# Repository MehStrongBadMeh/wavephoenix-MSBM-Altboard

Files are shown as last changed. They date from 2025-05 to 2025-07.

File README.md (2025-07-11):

<h1 align="center">
    WavePhoenix-MSBM-Altboard
</h1>

<p align="center">
    An alternate board design for the WavePhoenix Nintendo WaveBird open-source receiver 
</p>

<p align="center">
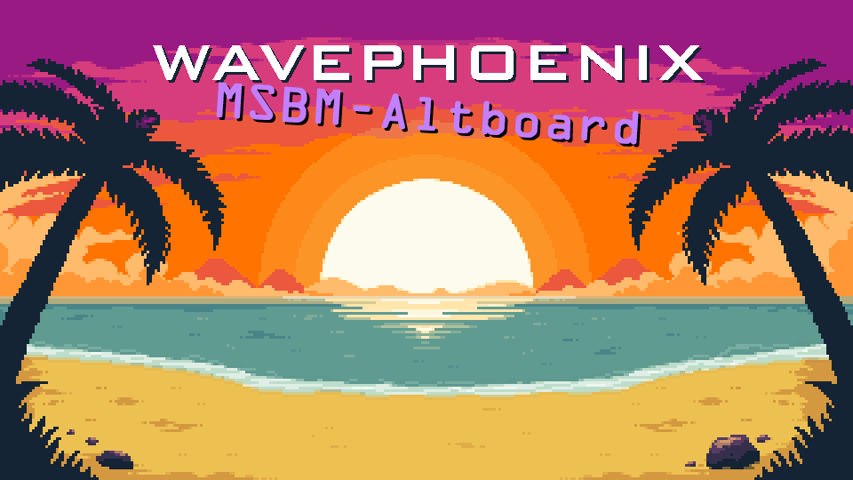
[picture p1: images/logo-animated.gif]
WavePhoenix-MSBM-Altboard
    
</p>

## Motivation

loopj's Wavephoenix receiver design relies on the RF-Star RF-BM-BG22C3 SoC, which quickly became out-of-stock everywhere, potentially due to people wanting them to make WavePhoenix receivers. So, I set out looking for an alternative. I ended up stumbling upon the [RF-BM-BG22A3](https://www.rfstariot.com/rf-bm-bg22a3-ble5-3-efr32bg22-module_p81.html) which utillizes the same SoC, in a slightly larger package. This means that, if wired properly, it could use the same firmware as the stock Wavephoenix board without modifications. All that was needed was an updated PCB design to utillize this alternate package, and a reworked case to fit the new PCB. The result is slightly bigger than the stock Wavephoenix, but still quite a bit smaller than the original Wavebird receiver.

As a bonus, the pcb antenna in the RF-BM-BG22A3 has great range. I have clocked over 40 feet of range without noticing dropouts.

## Firmware

The WavePhoenix-MSBM-Altboard is identical to the stock firmware of the WavePhoenix, [which can be found here](https://github.com/loopj/wavephoenix).

## Hardware

The hardware for the WavePhoenix-MSBM-Altboard receiver variant is available in the [`hardware/mini-receiver-msbm-altboard`](hardware/mini-receiver-msbm-altboard) directory. The receiver is similar to the reference WavePhoenix receiver other than the replacement of the RF-BM-BG22C3 with the RF-BM-BG22A3.

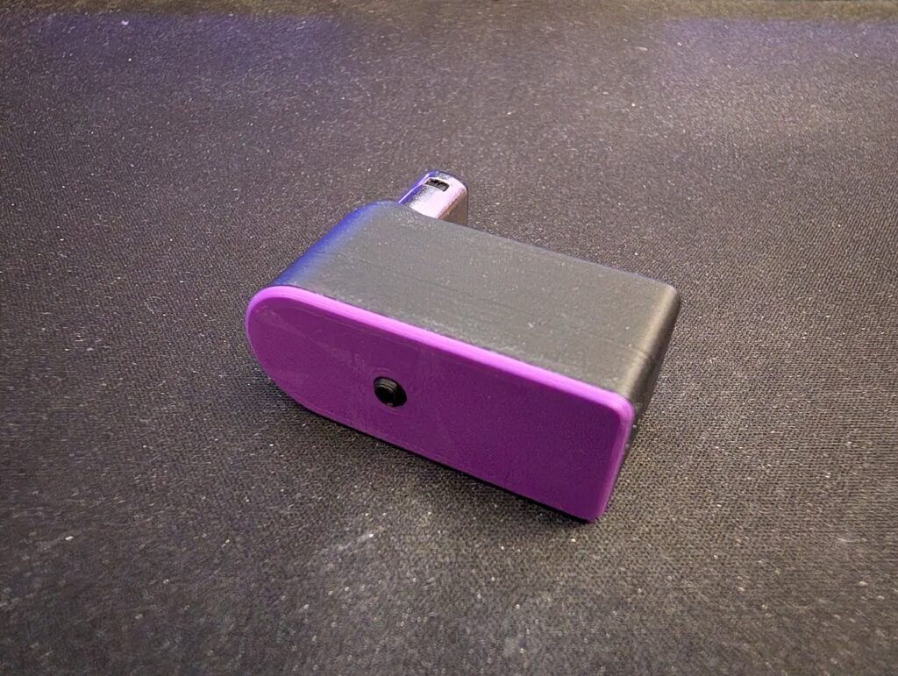
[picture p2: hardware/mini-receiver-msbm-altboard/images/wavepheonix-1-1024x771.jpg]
WavePhoenix-MSBM-Altboard Mini Receiver
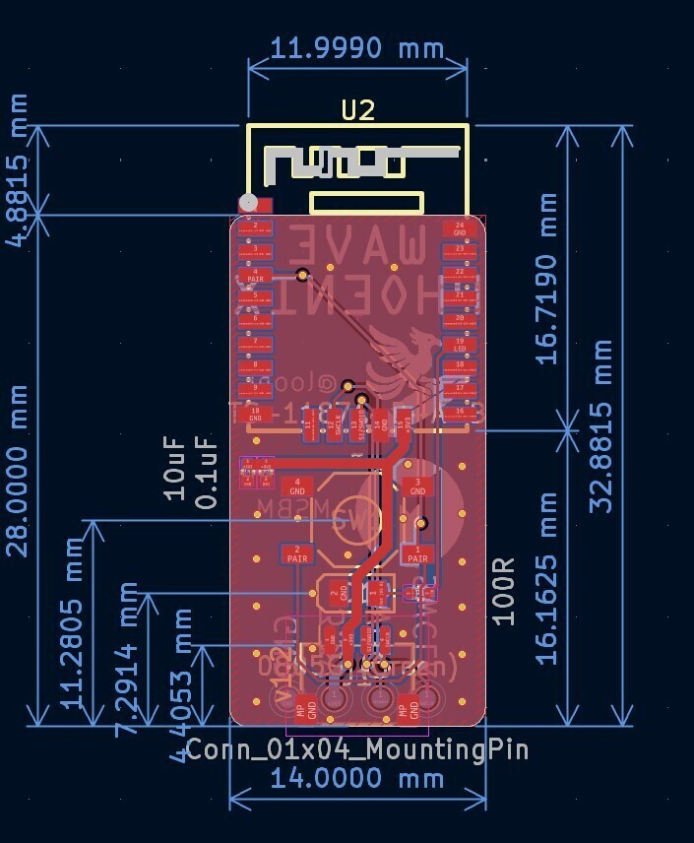
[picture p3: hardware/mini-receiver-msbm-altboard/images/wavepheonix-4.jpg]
WavePhoenix-MSBM-Altboard Mini Receiver
 

The hardware folder contains a simple PCB which hosts a [RF-BM-BG22A3](https://www.rfstariot.com/rf-bm-bg22a3-ble5-3-efr32bg22-module_p81.html) module, a pairing button, a status LED, and a JST connector for connecting to a GameCube controller port, as well as a 3D printable case.

- [`case`](hardware/mini-receiver-msbm-altboard/case) - 3D printable case for the receiver
- [`case-usb`](hardware/mini-receiver-msbm-altboard/case-usb) - 3D printable case for a special USB variant of the receiver
- [`gerbers`](hardware/mini-receiver-msbm-altboard/gerbers) - Gerber files for ordering the PCB
- [`KiCad`](hardware/mini-receiver-msbm-altboard/KiCad) - KiCad project files for the PCB

Check out the [`hardware/mini-receiver-msbm-altboard/README.md`](hardware/mini-receiver-msbm-altboard/README.md) for more information on how to build your own receiver based on this hardware variant.

## Special Thanks

- [loopj](https://github.com/loopj) - for creating the original WavePhoenix firmware and hardware that this variant is based on
- [dwillmore](https://github.com/dwillmore) and [unicab369](https://github.com/unicab369) - for giving me a crash course in using KiCad

## License

The hardware is licensed under the [Solderpad Hardware License v2.1](hardware/LICENSE).

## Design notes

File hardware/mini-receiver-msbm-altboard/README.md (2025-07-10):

# WavePhoenix-MSBM-Altboard Mini Receiver

The WavePhoenix-MSBM-Altboard Mini Receiver is a small, low-cost WaveBird receiver replacement based on the original WavePhoenix design. It has been designed to use an alternate chipset but otherwise function identically.

The receiver uses a cheap, off-the-shelf wireless module (the [RF-BM-BG22A3](https://www.rfstariot.com/rf-bm-bg22a3-ble5-3-efr32bg22-module_p81.html)), which can either be hand-wired, or assembled onto a custom PCB.

WavePhoenix-MSBM-Altboard Mini Receiver WavePhoenix-MSBM-Altboard Mini Receiver

## Differences

Functionally identical to the stock WavePhoenix other than:

- You need 1x RF-BM-BG22A3 module ([AliExpress](https://www.aliexpress.us/item/3256801502682253.html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), [LCSC](https://lcsc.com/product-detail/Bluetooth-Modules_RF-star-RF-BM-BG22A3_C5441203.html?s_z=n_RF-BM-BG22A3), [Tindie](https://www.tindie.com/products/rfstariot/efr32bg22-long-range-bluetooth-wireless-module/)) instead of the RF-BM-BG22C3
- The case has been designed to be used with a standard 1.6mm thick PCB instead of the 1.2mm thickness PCB the stock WavePhoenix was designed around.

## Build Guide

**This guide below is identical to the stock guide ([https://github.com/loopj/wavephoenix/tree/main/hardware/mini-receiver]), other than the differences listed above and some other minor additions**

### Parts

- Assembled Mini Receiver PCB - (see [PCB](#pcb))
- 3D printed case - (see [Case](#case))
- GameCube male connector - ([AliExpress](https://www.aliexpress.us/item/3256804501860592.html), [Alibaba](https://www.alibaba.com/product-detail/NGC-Gamecube-Male-Connector_1600107604838.html), [eBay](https://www.ebay.com/itm/354372477064))
- JST-SH 4-Pin connector with pre-crimped cable - ([AliExpress](https://www.aliexpress.us/item/3256803952186380.html), [Amazon](https://www.amazon.com/dp/B0D9WMLZ7B/))
- 1.5mm PMMA fiber cable - ([AliExpress](https://www.aliexpress.us/item/3256806278563564.html)) *or* 1.5mm diameter x 4mm light pipe - ([AliExpress](https://www.aliexpress.us/item/3256801194682892.html))
- Crimping tool or soldering iron (depending on the your connector type)

### Assembly

- Assemble the JST-SH to GameCube connector cable - (see [Cable](#cable))
- Flash the firmware - (see [Initial Firmware Flashing](#initial-firmware-flashing))
- Insert the GameCube connector into the case until it clicks into place
- Connect the JST-SH connector to the PCB
- Insert the PCB into the case, ensuring the LED and switch are aligned with the holes in the case, it should click into place
- Insert the light pipe into the small hole in the front of the case, if using PMMA fiber for the light pipe, cut it to size first (4mm)
- Insert the 3D printed button into the large hole in the front of the case
- Press the front of the case onto the back of the case

## PCB

The WavePhoenix Mini Receiver PCB is a simple carrier PCB for a RF-BM-BG22C3 module, tact switch, status LED, and a connector for the GameCube controller port.

### Ordering from JLCPCB, PCBWay, etc

You can find the gerber files in the [`gerbers`](gerbers) directory.

Order the PCB with the following settings:

- 2-layer board
- PCB thickness of **1.6mm**
- HASL is fine

### Bill of Materials

- **1x RF-BM-BG22A3 module ([AliExpress](https://www.aliexpress.us/item/3256801502682253.html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), [LCSC](https://lcsc.com/product-detail/Bluetooth-Modules_RF-star-RF-BM-BG22A3_C5441203.html?s_z=n_RF-BM-BG22A3), [Tindie](https://www.tindie.com/products/rfstariot/efr32bg22-long-range-bluetooth-wireless-module/))**
- 1x 0805 green LED
- 1x 5x5mm tactile switch
- 1x 4-pin JST-SH connector
- 1x 0402 100Ω resistor (adjust as needed)
- 1x 0402 10uF capacitor
- 1x 0402 0.1uF capacitor

You can find a [Mouser shared cart here](https://www.mouser.com/ProjectManager/ProjectDetail.aspx?AccessID=66aed3ee61). You'll need to source the RF-BM-BG22A3 module separately.

### Hand Assembly

The components should all be hand solderable, the smallest parts being the 0402 capacitors and resistor. If you are struggling with the capacitors, you can omit them, but it is recommended to include them.

I recommend using magnification, and soldering the RF-BM-BG22A3 module first, since the module is hard to solder once the capacitors are in place.

### PCB Assembly Services

If you want to use a PCB assembly service such as JLC PCBA, the CPL file and the BOM file are also found in the [`gerbers`](gerbers) directory.

**Notably, unlike the RF-BM-BG22C3, the RF-BM-BG22A3 qualifies for JLCPCB's Economic assembly, so this variant is considerably cheaper to get pre-assembled versus the stock WavePhoenix.**

## Case

A 3D printable case for the receiver can be found in the [`case`](case) directory. The case is designed to fit the assembled PCB and has a slot for the GameCube connector.

I recommend printing the parts in the default orientation of their STL.

## Case-USB

Oh ho ho, now what do we have here? Some kind of alternative case in the [`case-usb`](case-usb) that is designed to house both a WavePhoenix-MSBM-Altboard and a WaveShare RP2040-Zero. What purpose could that possbily serve? Guess you'll have to tune back in later to find out.

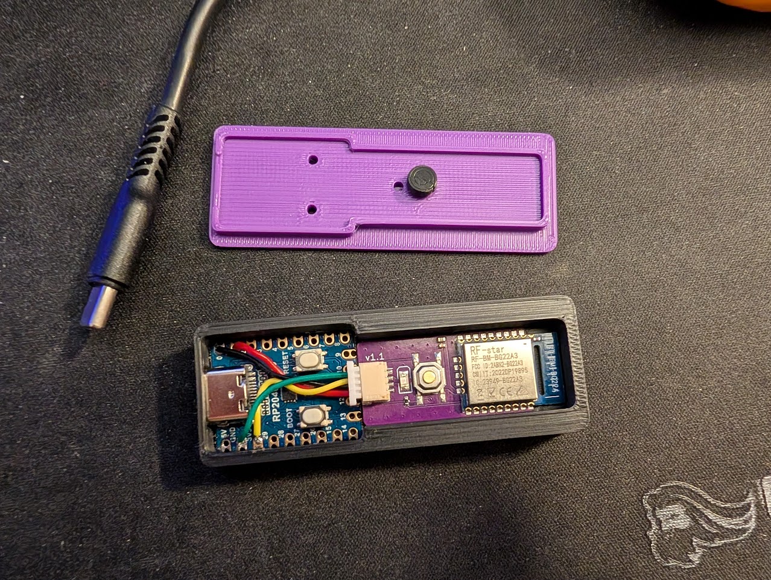
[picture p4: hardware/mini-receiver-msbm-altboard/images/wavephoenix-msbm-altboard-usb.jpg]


## Cable

> [!TIP]
> The [Fires Custom Controller](https://firescc.com/mod-guides#/diy-custom-cables) custom cable guide, covers the crimping the GameCube connector pins in detail!

Although we are using a 4-pin JST-SH connector, we only actually need 3 wires for the receiver. In the following photos, the ground wire is black, the power wire is red, and the data wire is blue, however the wire colors of pre-made JST cables vary *wildly*, so please check the pinout rather than relying on the wire colors in the photos.

Pin 1 on the JST-SH connector is indicated by a small triangle on the connector housing. In my photos below I have removed the unused wire from pin 4 of the JST-SH connector, but you can also leave it in place if you prefer.

First trim the wires on JST-SH connector cable to 30mm:

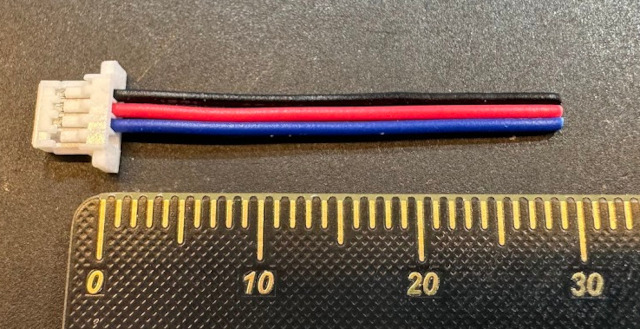
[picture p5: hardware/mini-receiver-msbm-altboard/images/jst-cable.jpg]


Strip a small amount of insulation (~1mm) off the ends of the wires, and crimp the wires to the GameCube connector pins.

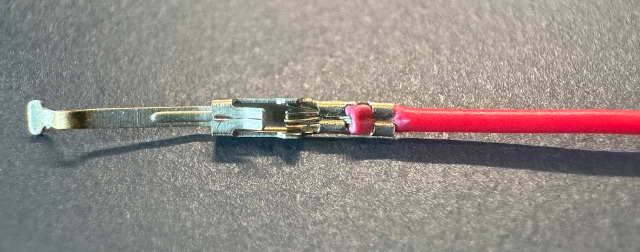
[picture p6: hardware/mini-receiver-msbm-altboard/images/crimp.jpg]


Insert the crimped pins into the GameCube connector housing in the following positions:

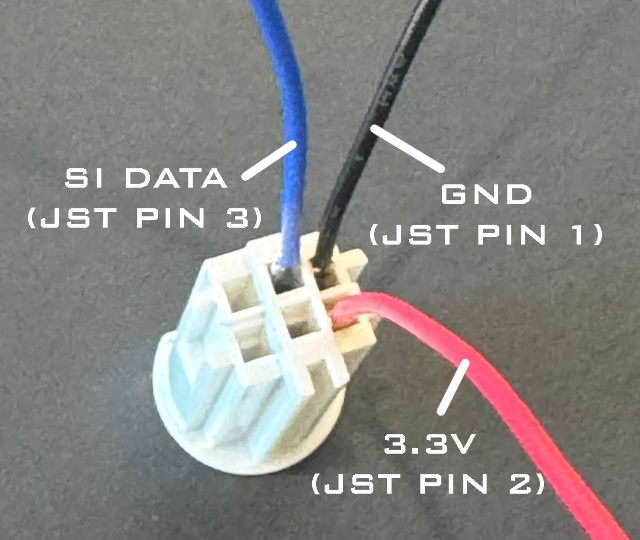
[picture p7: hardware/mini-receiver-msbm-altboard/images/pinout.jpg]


The “wings” on each pin should face towards the center of the plug, and the pins should be inserted until they click into place.

Next we need to trim off and file down the cable retention tabs on the metal GameCube connector housing:

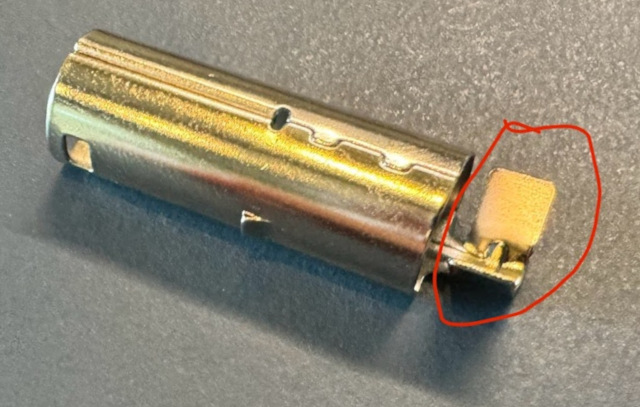
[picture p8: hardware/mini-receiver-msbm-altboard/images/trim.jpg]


We can then finally insert the plastic connector into the metal housing:

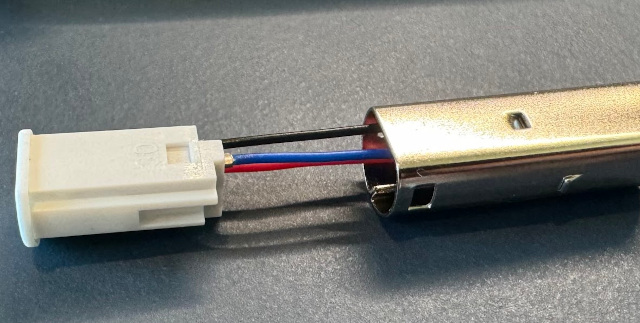
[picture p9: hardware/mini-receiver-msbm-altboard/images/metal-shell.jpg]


The complete assembly should look like this:

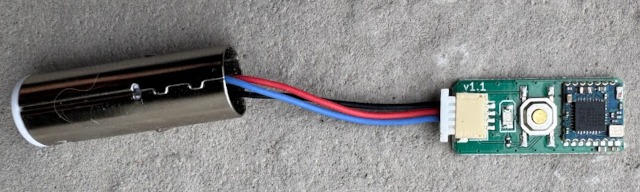
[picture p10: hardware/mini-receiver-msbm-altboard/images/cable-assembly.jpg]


## Initial Firmware Flashing

> [!NOTE]
> Once you have flashed the bootloader, you can use Bluetooth over-the-air updates to flash future firmware updates!

WavePhoenix receivers have two pieces of software running on them, the *bootloader* and the *application firmware*. The *bootloader* allows us to flash future application updates over Bluetooth, the *application firmware* is the program that handles WaveBird communication.

You can [find the latest bootloader and firmware here](https://github.com/loopj/wavephoenix/releases/latest), the WavePhoenix-MSBM-Altboard mini-receiver needs the `rf-bm-bg22c3` build of the firmware. **(Yes, the RF-BM-BG22A3 is compatible with it)**

The first-time flashing of the firmware requires a debug probe and some special software. If your WavePhoenix board already has the bootloader flashed, you can skip this part.

### Debug Probes

You'll need a SWD debug probe to flash the initial firmware onto the receiver. The debug probe connects to the receiver's SWD pins and allows you to flash the firmware using OpenOCD.

If you don't already have an SWD-capable debug probe, you can build one using a Raspberry Pi Pico. Instructions on how to build a debug probe using a Raspberry Pi Pico can be found in the [Appendix](#pi-pico-debug-probe).

### Pinouts

If you are flashing an assembled Mini Receiver board, the SWD pins are made available in two locations, pads on the back of the board, and via the 4-pin JST-SH connector.

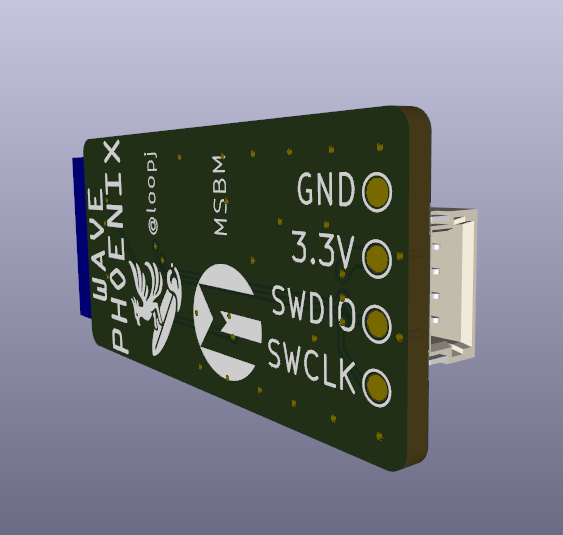
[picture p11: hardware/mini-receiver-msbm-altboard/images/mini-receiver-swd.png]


The pinout of the JST-SH connector is as follows:

| Pin | Function | Description |
| --- | --- | --- |
| 1 | GND | Ground |
| 2 | 3.3V | Power |
| 3 | SWDIO | SWD Data / GameCube Data |
| 4 | SWCLK | SWD Clock |

### OpenOCD

To flash the firmware, you'll need to install Arduino's fork of OpenOCD, which adds support for EFR32 Series 2 SoCs.

Prebuilt binaries are available for [Windows](https://downloads.arduino.cc/tools/openocd-0.12.0-arduino1-static-i686-w64-mingw32.tar.bz2), [macOS](https://downloads.arduino.cc/tools/openocd-0.12.0-arduino1-static-x86_64-apple-darwin19.tar.bz2), and [Linux](https://downloads.arduino.cc/tools/openocd-0.12.0-arduino1-static-x86_64-ubuntu16.04-linux-gnu.tar.bz2).

The source for this fork is available on [GitHub here](https://github.com/facchinm/OpenOCD/tree/arduino-0.12.0-rtx5).

### Flashing

Once you have OpenOCD installed, you can flash the bootloader and application firmware using the following commands:

#### Erase the device

First we'll need to do a full device erase:

```bash
# Linux / macOS
openocd -f "interface/cmsis-dap.cfg" \
        -f "target/efm32s2.cfg" \
        -c "init; efm32s2_dci_device_erase; shutdown"
```

```powershell
# Windows (PowerShell)
openocd.exe -f "interface\cmsis-dap.cfg" `
            -f "target\efm32s2.cfg" `
            -c "init; efm32s2_dci_device_erase; shutdown"
```

> [!IMPORTANT]  
> Disconnect then reconnect the debug probe to the receiver before proceeding to the next step.

#### Flash the bootloader

Then we can flash the bootloader:

```bash
# Linux / macOS
openocd -f "interface/cmsis-dap.cfg" \
        -c "transport select swd" \
        -f "target/efm32s2.cfg" \
        -c "init; halt; flash write_image erase bootloader.hex; exit"
```

```powershell
# Windows (PowerShell)
openocd.exe -f "interface\cmsis-dap.cfg" `
            -c "transport select swd" `
            -f "target\efm32s2.cfg" `
            -c "init; halt; flash write_image erase bootloader.hex; exit"
```

> [!TIP]  
> From this point on, you can now use Bluetooth over-the-air updates to flash new application firmware!

#### Flash the application

Since we already have the device wired up, we can also flash the receiver application using SWD:

```bash
# Linux / macOS
openocd -f interface/cmsis-dap.cfg \
        -c "transport select swd" \
        -f target/efm32s2.cfg \
        -c "init; halt; flash write_image erase receiver.hex; exit"
```

```powershell
# Windows
openocd.exe -f interface\cmsis-dap.cfg `
            -c "transport select swd" `
            -f target\efm32s2.cfg `
            -c "init; halt; flash write_image erase receiver.hex; exit"
```

You should now have a fully functional WavePhoenix receiver!

## Usage

### Pairing

WavePhoenix receivers use "virtual pairing" instead of the original WaveBird’s channel wheel. To initiate pairing, press the receiver’s pairing button. The onboard LED will start blinking to indicate the receiver is now in pairing mode. Press and hold X + Y on the WaveBird controller to pair a WaveBird to a receiver. Once pairing is successful, the LED will stop blinking and remain solid.

### Entering Bootloader Mode

You can enter the bootloader for OTA updates in two ways:

1. Press and hold the pairing button for more than 3 seconds, until the LED turns off
2. Press and hold the pairing button while plugging in the receiver

### Upgrading Firmware

You can always find the latest receiver firmware in the [latest release](https://github.com/loopj/wavephoenix/releases/latest) on GitHub. The firmware is available in two formats, a `.gbl` file for over-the-air updates, and a `.hex` file for flashing via SWD.

The mini receiver uses the `rf-bm-bg22c3` build of the firmware, which is specifically designed for the RF-BM-BG22C3 module.

#### Using the WavePhoenix Web App

If you have a computer with Bluetooth or an Android phone, you can use the [WavePhoenix Web App](https://web.wavephoenix.com) in Google Chrome to flash the firmware.

#### Using the WavePhoenix CLI

If you have a computer with Bluetooth, you can also use the [WavePhoenix CLI](https://github.com/loopj/wavephoenix-cli) to flash the firmware:

```bash
wavephoenix flash firmware.gbl
```

#### Using the Simplicity Connect app

Another option is to use the [Simplicity Connect mobile app](https://www.silabs.com/developer-tools/simplicity-connect-mobile-app?tab=downloads) to flash the firmware.

#### Flashing via SWD

You can also always use SWD to re-flash the firmware, as described in the [Initial Firmware Flashing](#initial-firmware-flashing) section.

## Appendix

### Pi Pico Debug Probe

If you have a Raspberry Pi Pico, you can use it as a debug probe to flash WavePhoenix firmware. The Pico is a low-cost (~$4) microcontroller board that can be used as a debug probe with OpenOCD.

Download the latest `debugprobe_on_pico.uf2` from the [Raspberry Pi Debug Probe repo](https://github.com/raspberrypi/debugprobe/releases/latest) and flash it to your Pico by dragging the file onto the Pico's USB drive. Once you have flashed the firmware, the Pico will now be available to use as a debug probe with OpenOCD.

Here's the pinout for SWD programming:

Pi Pico Debug Probe

### Flipper Zero Debug

If you are me, then you just used your Flipper Zero as a debug probe, just use the [Dap Link](https://lab.flipper.net/apps/dap_link) app and hook up the pins to the pins you selected in the app for SWC SWD.

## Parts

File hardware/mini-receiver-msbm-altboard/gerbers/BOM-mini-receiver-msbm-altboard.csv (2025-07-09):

Designator | Footprint | Quantity | Value | LCSC Part #
C1 | 0402 | 1 | 0.1uF | C1525
C2 | 0402 | 1 | 10uF | C15525
D1 | LED0805-R-RD | 1 | 0805G (Green) | C2297
J1 | JST_SH_SM04B-SRSS-TB_1x04-1MP_P1.00mm_Horizontal | 1 | Conn_01x04_MountingPin | C160404
R1 | 0402 | 1 | 100R | C25076
SW1 | SW-SMD_4P-L5.1-W5.1-P3.70-LS6.5-TL-2 | 1 | TS-1187A-B-A-B | C318884
U2 | BULETM-SMD_RF-BM-BG22A1 | 1 | ~ | C5441203

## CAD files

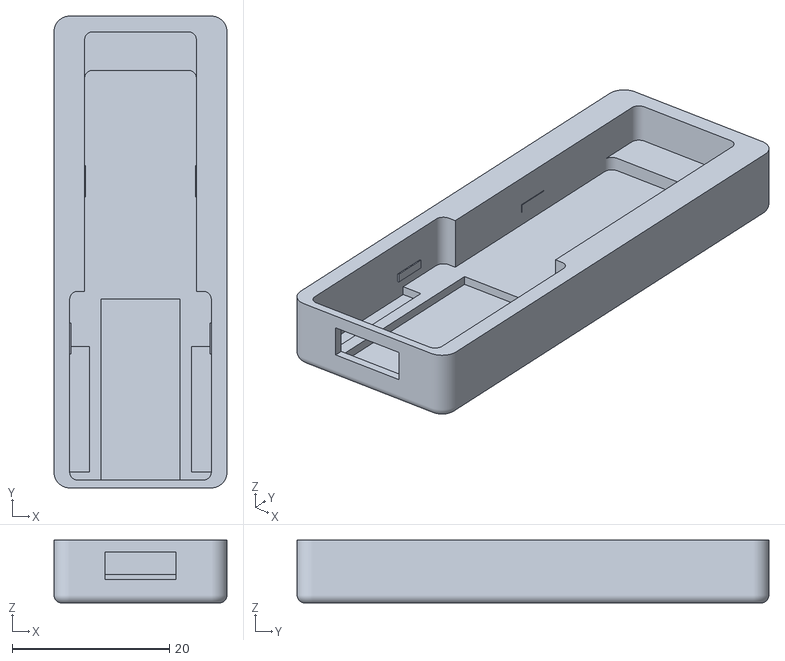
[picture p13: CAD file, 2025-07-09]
hardware/mini-receiver-msbm-altboard/case-usb/WavePhoenix-MSBM-Altboard-with-rp2040-zero-main.stl
22.0 x 60.0 x 8.00

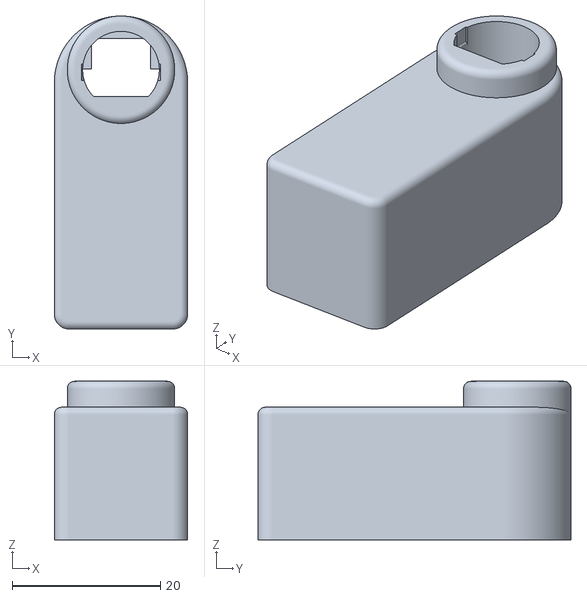
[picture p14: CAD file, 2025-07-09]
hardware/mini-receiver-msbm-altboard/case/WavePhoenix-MSBM-Altboard-main.stl
18.0 x 42.2 x 21.4

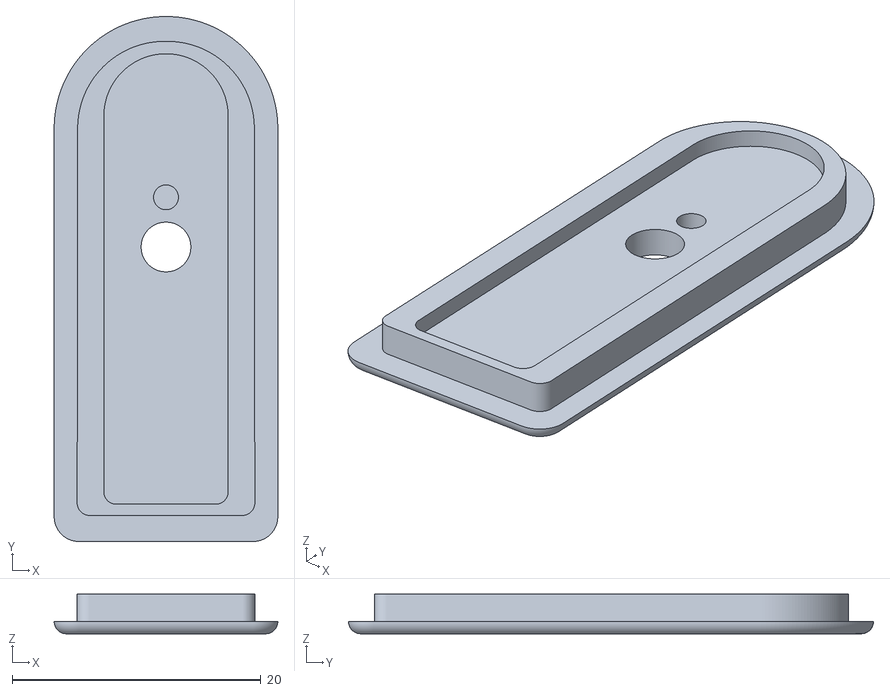
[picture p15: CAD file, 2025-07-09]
hardware/mini-receiver-msbm-altboard/case/WavePhoenix-MSBM-Altboard-cover.stl
18.0 x 42.2 x 3.20

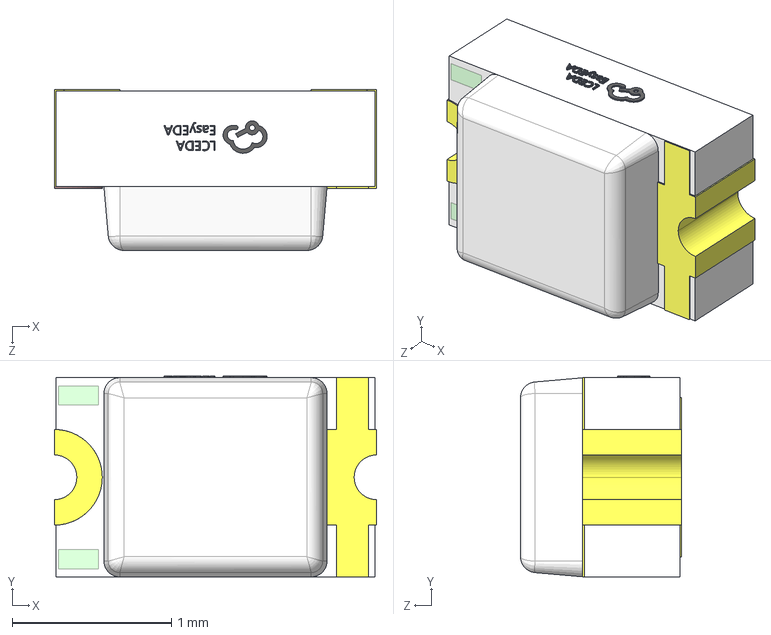
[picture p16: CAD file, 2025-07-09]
hardware/mini-receiver-msbm-altboard/KiCad/project-footprints/LED0805-RD.step
2.02 x 1.26 x 1.01 mm

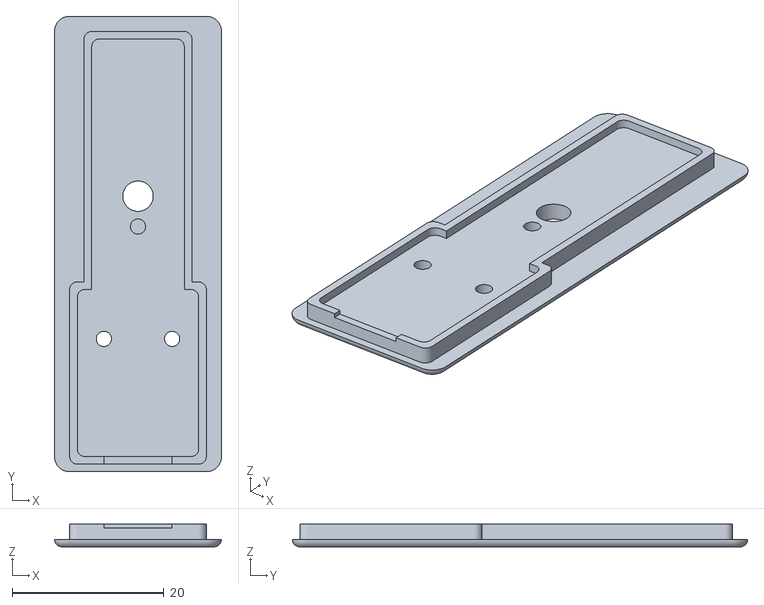
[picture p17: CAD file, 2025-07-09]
hardware/mini-receiver-msbm-altboard/case-usb/WavePhoenix-MSBM-Altboard-with-rp2040-zero-cover.stl
22.0 x 60.0 x 3.00

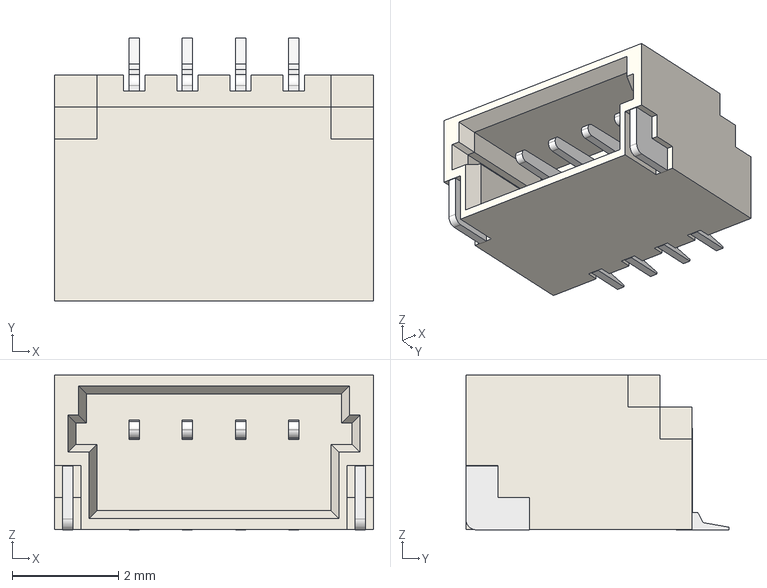
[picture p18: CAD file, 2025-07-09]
hardware/mini-receiver-msbm-altboard/KiCad/project-footprints/CONN-SMD_SR1.00-WS-4P.step
6.00 x 4.95 x 2.91 mm

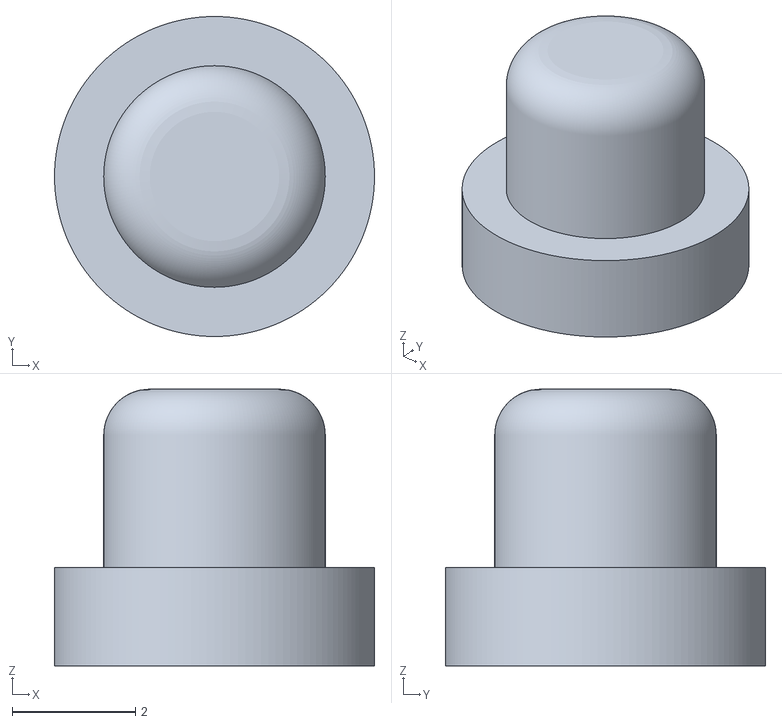
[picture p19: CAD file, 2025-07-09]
hardware/mini-receiver-msbm-altboard/case-usb/WavePhoenix-MSBM-Altboard-with-rp2040-zero-button.stl
5.20 x 5.20 x 4.50

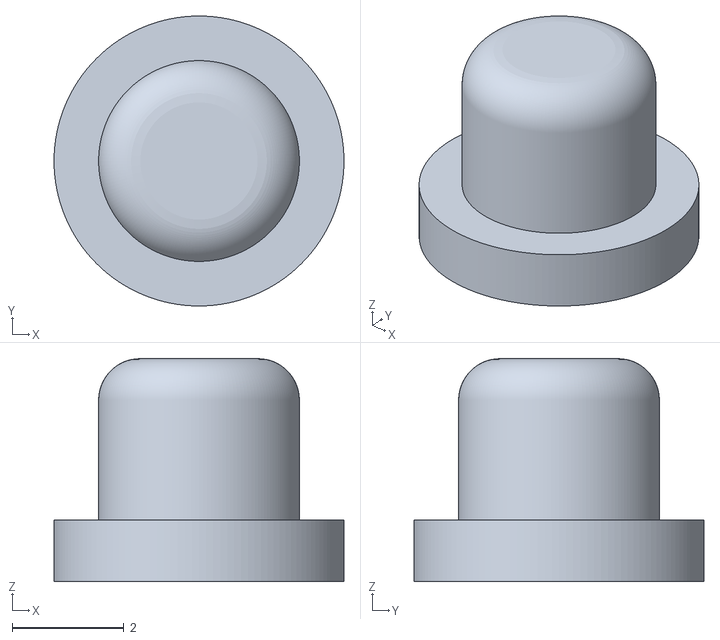
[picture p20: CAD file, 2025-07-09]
hardware/mini-receiver-msbm-altboard/case/WavePhoenix-MSBM-Altboard-button.stl
5.20 x 5.20 x 4.00

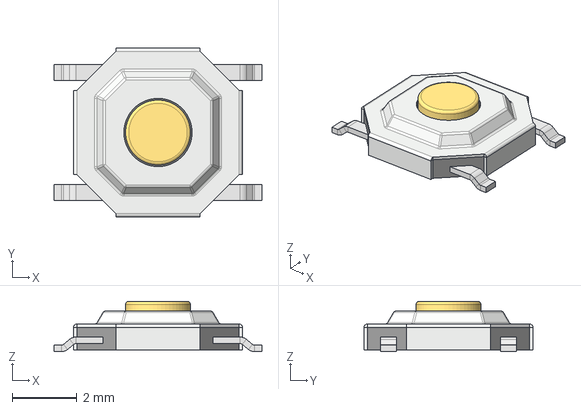
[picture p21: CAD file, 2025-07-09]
hardware/mini-receiver-msbm-altboard/KiCad/project-footprints/KEY-SMD_4P-L5.2-W5.2-H1.5-LS6.4-P3.70.step
6.40 x 5.20 x 1.55 mm

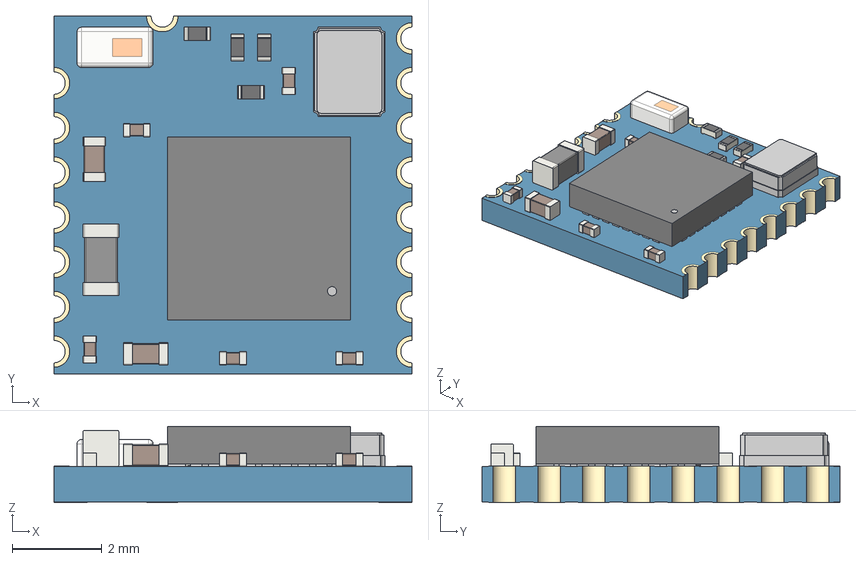
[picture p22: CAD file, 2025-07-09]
hardware/mini-receiver-msbm-altboard/KiCad/project-footprints/RF-BM-BG22C3.step
8.00 x 8.00 x 1.70 mm
Antenna
product
C_0201_0603Metric x 5
L_0603_1608Metric
C_0402_1005Metric x 2
R_0201_0603Metric x 4

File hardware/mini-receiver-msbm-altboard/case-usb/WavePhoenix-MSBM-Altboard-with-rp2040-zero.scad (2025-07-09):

//Requires https://github.com/Irev-Dev/Round-Anything
include <Round-Anything/polyround.scad>

$fn = $preview ? 32 : 128;

//building pallete
show_building_pallete = true;
if (show_building_pallete)
{
    rotate([0,0,180]) translate([-9,0,1.0913]) rp2040_zero();
    translate([-7,0,0]) wavephoenix_board();
    case_main();
    translate([0,0,16]) case_cover();
    translate([0,11.3,3.2+5]) case_button();
}

//printing pallate
//case_main();
//translate([0,0,1]) rotate([0,180,0]) case_cover();
//case_button();

module wavephoenix_board()
{
    //mainboard
    color("purple") linear_extrude(1.6)
        polygon(polyRound([[0,0,1],[14,0,1],[14,28,1],[0,28,1]],10));
    
    //RF-BM-BG22A3
    translate([1,16.1625,1.6]) union()
    {
        difference()
        {
            color("blue") cube([12,16.7,0.76]);
            translate([2,12.5,-0.1]) linear_extrude(1)
            {
                polygon(polyRound([[0,0,0.5],[8,0,0.5],[8,1,0.5],[0,1,0.5]],10));
            }
        }
        
        color("grey") translate([1,1,0.5]) cube([10,11,2.2-0.5]);
    }
    
    //button
    translate([7,11.3,1.6]) import("G:/PCB/WavePhoenix/wavephoenix-main/hardware/mini-receiver/KiCad - Altboard/project-footprints/KEY-SMD_4P-L5.2-W5.2-H1.5-LS6.4-P3.70.stl");
    
    //led
    color("green") translate([7,7.3,1.6]) import("G:/PCB/WavePhoenix/wavephoenix-main/hardware/mini-receiver/KiCad - Altboard/project-footprints/LED0805-RD.stl");
    
    //connector
    translate([5.45,2.2,1.6]) import("G:/PCB/WavePhoenix/wavephoenix-main/hardware/mini-receiver/KiCad - Altboard/project-footprints/CONN-SMD_SR1.00-WS-4P.stl");
}

module rp2040_zero()
{
    color("blue") import("G:/CAD/RP2040_Zero_stp/ImageToStl.com_RP2040_Zero/RP2040_Zero.stl");
}

module case_main()
{
    difference()
    {
        //main body
        translate([0,0,-2]) polyRoundExtrude([[-11,-25,2],[11,-25,2],[11,35,2],[-11,35,2]],8,0,1,$preview ? 10 : 40);
        //wavepheenix cut
        translate([0,0,6.9]) rotate([180,0,0]) union()
        {
            translate([0,0,-0.1]) polyRoundExtrude([[-7.1,-33,1],[7.1,-33,1],[7.1,5.25,1],[-7.1,5.25,1]],7-1.59,0,0,$preview ? 10 : 40); //board carve-out
            translate([0,0,-0.1]) polyRoundExtrude([[-7.1,-28.1,1],[7.1,-28.1,1],[7.1,5.25,1],[-7.1,5.25,1]],7,0,0,$preview ? 10 : 40); //deep board carve-out
        }
        polyRoundExtrude([[-9,-24,1],[9,-24,1],[9,0,1],[-9,0,1]],7,0,0,$preview ? 10 : 40); //rp2040-zero cut
        translate([-9/2,-27,1]) cube([9,8,3.5]); //usbc cut
        translate([-10/2,-24,-1]) cube([10,23,2]); //rp2040-zero basement
        translate([5+1.5,-23,-1]) cube([2.5,16,2]); //rp2040-zero wire basement
        translate([-(5+1.5)-2.5,-23,-1]) cube([2.5,16,2]); //rp2040-zero wire basement
    }
    //wavephoenix retention tabs
    translate([0,14,0.5+1.6]) union()
    {
        translate([-7.1,0,0]) cube([0.2,4,1], true);
        translate([7.1,0,0]) cube([0.2,4,1], true);
    }
    //rp2040-zero retention tabs
    translate([0,-6,0.5+1.1]) union()
    {
        translate([-9,0,0]) cube([0.3,4,1], true);
        translate([9,0,0]) cube([0.3,4,1], true);
    }
}

module case_cover()
{
    //color("red") rotate([180,0,0]) polyRoundExtrude([[-7.1,-33,1],[7.1,-33,1],[7.1,5.25,1],[-7.1,5.25,1]],1,0,0,$preview ? 10 : 40); //wave phoenix cut
    //color("red") translate([0,0,-1]) polyRoundExtrude([[-9,-24,1],[9,-24,1],[9,0,1],[-9,0,1]],2,0,0,$preview ? 10 : 40); //rp2040-zero cut
    difference()
    {
        union()
        {
            //main
            polyRoundExtrude([[-11,-25,2],[11,-25,2],[11,35,2],[-11,35,2]],1,1,0,$preview ? 10 : 40);
            //grip
            translate([0,0,-2]) linear_extrude(3) polygon(polyRound([[9,-24,1],[-9,-24,1],[-9,0,1],[-7.1,0,0],[-7.1,33,1],[7.1,33,1],[7.1,0,0],[9,0,1]],10));            
        }

        //grip cut
        translate([0,0,-4]) linear_extrude(3) polygon(polyRound([[8,-23,1],[-8,-23,1],[-8,-1,1],[-6.1,-1,0],[-6.1,32,1],[6.1,32,1],[6.1,-1,0],[8,-1,1]],10));
        //usbc cut
        translate([-9/2,-27,-5]) cube([9,8,3.5]); 
        //buton hole
        translate([0,11.3,-2]) cylinder(4,r=2); 
        //led hole
        translate([0,7.3,-2]) cylinder(2.6,r=1);
        //buton hole 1
        translate([4.5,-7.5,-2]) cylinder(4,r=1);
        //buton hole 2
        translate([-4.5,-7.5,-2]) cylinder(4,r=1); 
    }
}

module case_button()
{
    cylinder(1.6,r=2.6);
    polyRoundExtrude([[-1.8,-1.8,1.8],[1.8,-1.8,1.8],[1.8,1.8,1.8],[-1.8,1.8,1.8]],4.5,0.75,0,$preview ? 10 : 40);
}

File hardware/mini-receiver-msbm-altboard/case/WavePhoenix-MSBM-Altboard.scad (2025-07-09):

//Requires https://github.com/Irev-Dev/Round-Anything
include <Round-Anything/polyround.scad>

$fn = $preview ? 32 : 128;

//building pallete
show_building_pallete = true;
if (show_building_pallete)
{
    translate([-7,0,5.9]) rotate([180,0,0]) wavephoenix_board();
    case_main();
    translate([0,0,-10]) rotate([0,180,0]) case_cover();
    translate([0,-11.3,2.8-5]) rotate([0,180,0]) case_button();
}

//printing pallate
//case_main();
//translate([0,0,1]) rotate([0,180,0]) case_cover();
//case_button();

module wavephoenix_board()
{
    //mainboard
    color("purple") linear_extrude(1.6)
        polygon(polyRound([[0,0,1],[14,0,1],[14,28,1],[0,28,1]],10));
    
    //RF-BM-BG22A3
    translate([1,16.1625,1.6]) union()
    {
        difference()
        {
            color("blue") cube([12,16.7,0.76]);
            translate([2,12.5,-0.1]) linear_extrude(1)
            {
                polygon(polyRound([[0,0,0.5],[8,0,0.5],[8,1,0.5],[0,1,0.5]],10));
            }
        }
        
        color("grey") translate([1,1,0.5]) cube([10,11,2.2-0.5]);
    }
    
    //button
    translate([7,11.3,1.6]) import("G:/PCB/WavePhoenix/wavephoenix-main/hardware/mini-receiver/KiCad - Altboard/project-footprints/KEY-SMD_4P-L5.2-W5.2-H1.5-LS6.4-P3.70.stl");
    
    //led
    color("green") translate([7,7.3,1.6]) import("G:/PCB/WavePhoenix/wavephoenix-main/hardware/mini-receiver/KiCad - Altboard/project-footprints/LED0805-RD.stl");
    
    //connector
    translate([5.45,2.2,1.6]) import("G:/PCB/WavePhoenix/wavephoenix-main/hardware/mini-receiver/KiCad - Altboard/project-footprints/CONN-SMD_SR1.00-WS-4P.stl");
}


/*difference()
{
    color("red") translate([0,0,5.825+0.4]) import("G:/PCB/WavePhoenix/wavephoenix-main/hardware/mini-receiver/case/Main Case.stl");
    translate([-10,-30,0]) cube([10,40,40]); 
}*/
//color("red") translate([0,0,0.4]) import("G:/PCB/WavePhoenix/wavephoenix-main/hardware/mini-receiver/case/Main Case chop.stl");


module case_main()
{
    difference()
    {
        union()
        {
            //gamecube connector
            translate([0,0,5.9+1]) polyRoundExtrude([[-7.25,-7.25,7.25],[7.25,-7.25,7.25],[7.25,7.25,7.25],[-7.25,7.25,7.25]],21.4-5.9-1,1,0,$preview ? 10 : 40);
            //main body
            polyRoundExtrude([[-9,-35,2],[9,-35,2],[9,7.25,9],[-9,7.25,9]],17.9,1,0,$preview ? 10 : 40);
        }
        
        //Gamecube connector carve-out
        union()
        {
            difference()
            {
                translate([0,0,0]) cylinder(22, r=5.174);
                
                translate([-7,-6.625,-1]) cube([14,3,24]);
            }
            translate([0,0.775,22]) rotate([90,0,0]) linear_extrude(2.2)
                polygon([[-5.32766,-2.6],[0,-11.82],[5.32766,-2.6],[5.32766,1],[-5.32766,1]]);
            translate([0,0.775,20.3]) rotate([90,0,0]) linear_extrude(2.2)
                polygon([[-5.32766,-2.6],[0,-49.86],[5.32766,-2.6]]);
        }
        //board carve-out
        translate([0,0,-0.1]) polyRoundExtrude([[-7.1,-33,1],[7.1,-33,1],[7.1,5.25,7],[-7.1,5.25,7]],6-1.59,0,0,$preview ? 10 : 40);
        //deep board carve-out
        translate([0,0,-0.1]) polyRoundExtrude([[-7.1,-28.1,1],[7.1,-28.1,1],[7.1,5.25,7],[-7.1,5.25,7]],6,0,0,$preview ? 10 : 40);
    }
    //connector retention tab
    translate([-4,4.2211,3.895]) cube([8,2,2]);
    //board retention tabs - front
    translate([0,0,3.895]) linear_extrude(2)
        polygon([[-4,0.1],[-8,0.1],[-4,6]]);
    translate([0,0,3.895]) linear_extrude(2)
        polygon([[4,0.1],[8,0.1],[4,6]]);
    //board retention tabs - top
    translate([-7.1,-14,5.9-0.5-1.6]) cube([0.2,4,1], true);
    translate([7.1,-14,5.9-0.5-1.6]) cube([0.2,4,1], true);
}

module case_cover()
{
    difference()
    {
        union()
        {
            //main
            polyRoundExtrude([[-9,-35,2],[9,-35,2],[9,7.25,9],[-9,7.25,9]],1,1,0,$preview ? 10 : 40);
            //interiorgrip
            translate([0,0,-2.2]) polyRoundExtrude([[-7.15,-32.9,1],[7.15,-32.9,1],[7.1,5.25,7],[-7.1,5.25,7]],3.2,0,0,$preview ? 10 : 40);
        }
        //buton hole
        translate([0,-11.3,-2]) cylinder(4,r=2);
        //led hole
        translate([0,-7.3,-2]) cylinder(2.6,r=1);
        //interior cutout
        translate([0,0,-2.2-1]) polyRoundExtrude([[-5,-32,1],[5,-32,1],[5,4.25,6],[-5,4.25,6]],1.2+1,0,0,$preview ? 10 : 40);
    }
}

module case_button()
{
    cylinder(1.1,r=2.6);
    polyRoundExtrude([[-1.8,-1.8,1.8],[1.8,-1.8,1.8],[1.8,1.8,1.8],[-1.8,1.8,1.8]],4,0.75,0,$preview ? 10 : 40);
}

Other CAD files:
hardware/mini-receiver-msbm-altboard/KiCad/project-footprints/CONN-SMD_SR1.00-WS-4P.stl
hardware/mini-receiver-msbm-altboard/KiCad/project-footprints/KEY-SMD_4P-L5.2-W5.2-H1.5-LS6.4-P3.70.stl
hardware/mini-receiver-msbm-altboard/KiCad/project-footprints/LED0805-RD.stl

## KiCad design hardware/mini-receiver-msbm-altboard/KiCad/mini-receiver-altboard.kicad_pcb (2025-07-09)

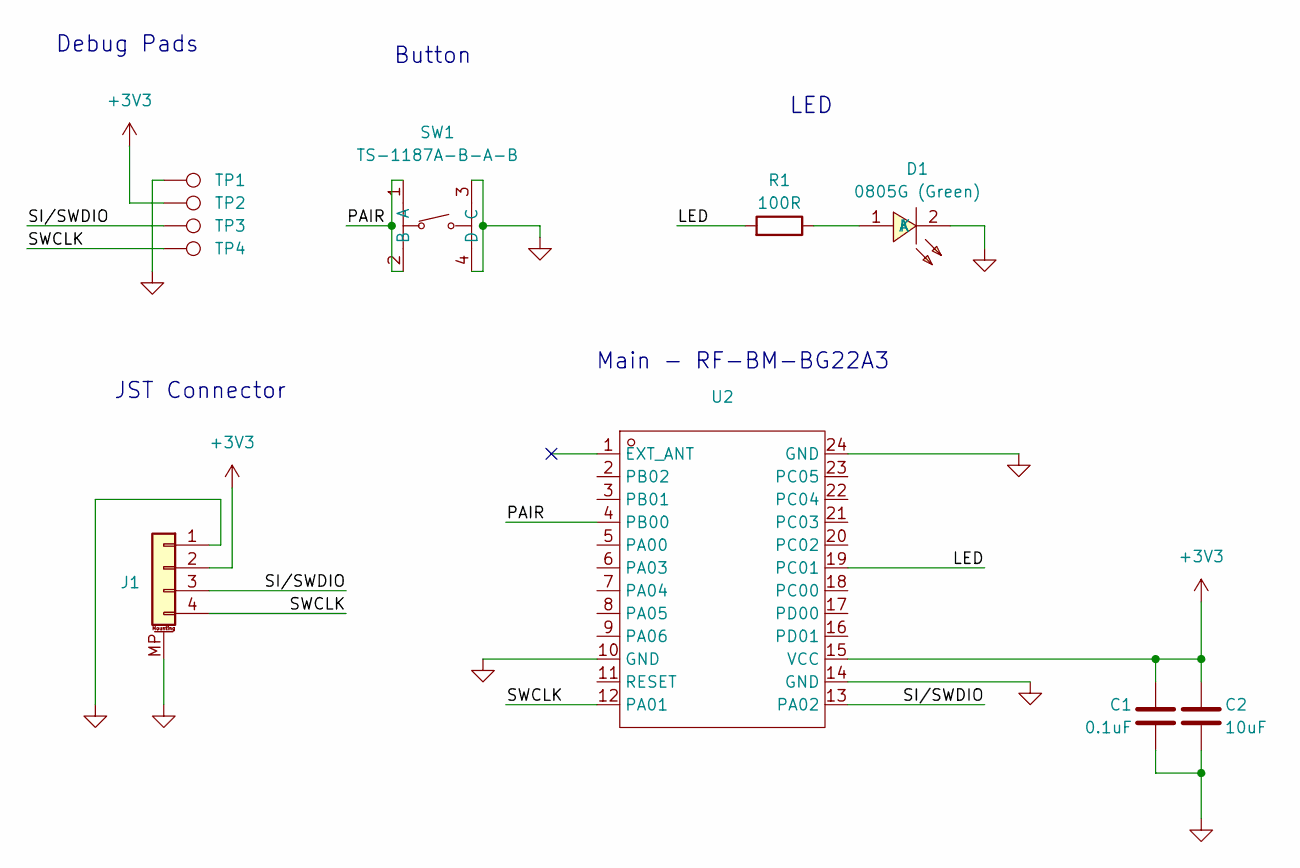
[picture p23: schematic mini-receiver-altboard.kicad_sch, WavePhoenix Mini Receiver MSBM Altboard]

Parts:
C1: 0.1uF; C_0402_1005Metric; LCSC C1525
C2: 10uF; C_0402_1005Metric; LCSC C15525
D1: 0805G (Green); LED0805-R-RD; LCSC Part C2297
J1: Conn_01x04_MountingPin; JST_SH_SM04B-SRSS-TB_1x04-1MP_P1.00mm_Horizontal; LCSC C160404
R1: 100R; R_0402_1005Metric; LCSC C25076
SW1: TS-1187A-B-A-B; SW-SMD_4P-L5.1-W5.1-P3.70-LS6.5-TL-2; LCSC Part C318884
TP1: G; TestPoint_Pad_D1.0mm
TP2: V; TestPoint_Pad_D1.0mm
TP3: D; TestPoint_Pad_D1.0mm
TP4: C; TestPoint_Pad_D1.0mm
U2: BULETM-SMD_RF-BM-BG22A1; Manufacturer Part RF-BM-BG22A3; LCSC Part Name EFR32BG22串口透传I2C透传蓝牙模块

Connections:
+3V3: C1.1, C2.1, J1.2, TP2.1, U2.15 (VCC)
/LED: R1.2, U2.19 (PC01)
/PAIR: SW1.1 (A), SW1.2 (B), U2.4 (PB00)
/SI/SWDIO: J1.3, TP3.1, U2.13 (PA02)
/SWCLK: J1.4, TP4.1, U2.12 (PA01)
GND: C1.2, C2.2, D1.2 (K), J1.1, J1.MP (MountPin), SW1.3 (C), SW1.4 (D), TP1.1, U2.10 (GND), U2.14 (GND), U2.24 (GND)
unnamed: D1.1 (A), R1.1

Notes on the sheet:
Debug Pads
Main - RF-BM-BG22A3
LED
Button
JST Connector

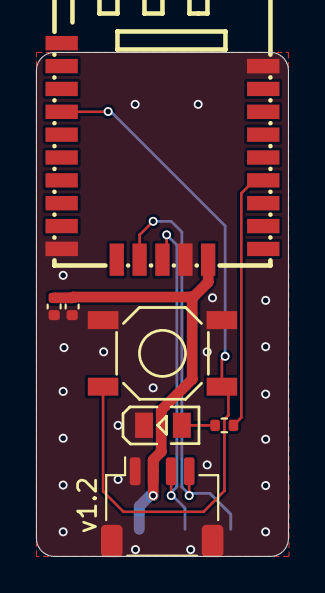
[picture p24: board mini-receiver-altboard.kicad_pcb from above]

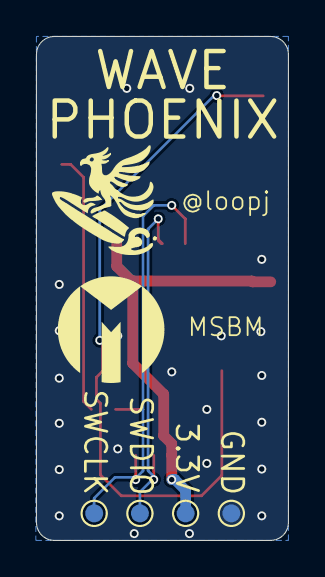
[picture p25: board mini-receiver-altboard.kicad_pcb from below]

Board: 2 copper layers, 14.0 x 28.0 mm, 11 parts (4 on the bottom side), 7 nets.

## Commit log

2025-05-28 Implement stub 'probe device' SI command
2025-07-09 Replace with WavePhoenix-MSBM-Altboard
    [BOM-mini-receiver-msbm-altboard.csv, BOM-mini-receiver.csv, Button Actuator.stl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]
2025-07-10 Recommend the Arduino fork of openocd
